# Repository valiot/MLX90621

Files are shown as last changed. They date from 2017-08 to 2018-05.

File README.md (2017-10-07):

### MLX90621 Arduino and Processing example code

Arduino and Processing code for the Melexis [MLX90621](http://www.melexis.com/Infrared-Thermometer-Sensors/Infrared-Thermometer-Sensors/Low-noise-high-speed-16x4-Far-Infrared-array-823.aspx) 16x4 thermopile array.

Includes R script to parse data files (which can be exported by Processing visualizer).

The MLX90621 FIRray temperature sensing device from Melexis utilizes the company’s non-contact temperature measurement technology to create a highly cost-effective thermography solution. Covering a -20°C to 300°C temperature range, this 16 x 4 element far infrared (FIR) thermopile sensor array produces a map of heat values for the target area in real time, avoiding the need to scan the area with a single point sensor or use an expensive microbolometer device.

In use in VU and Tilburg University temperature [cry detection project](http://www.pavlov.io/2015/07/01/detecting-crying-eyes/).

Implements MaxBot's MLX90621 [Arduino library](http://forum.arduino.cc/index.php?topic=126244.0) patched with KMoto's [minor change](http://forum.arduino.cc/index.php?topic=126244.msg2307588#msg2307588) in defaultConfig_H.

Also makes use of [nox771's i2c_t3 enhanced Teensy 3 Wire library](https://github.com/nox771/i2c_t3). This library allows a [Teensy 3.1](https://www.pjrc.com/store/teensy31.html) Arduino compatible USB development board to communicate with the MLX90621 over I2C/TWI.

TODO 2015-10-25: Refactor and clean up Processing visualizer.

##### Screenshot

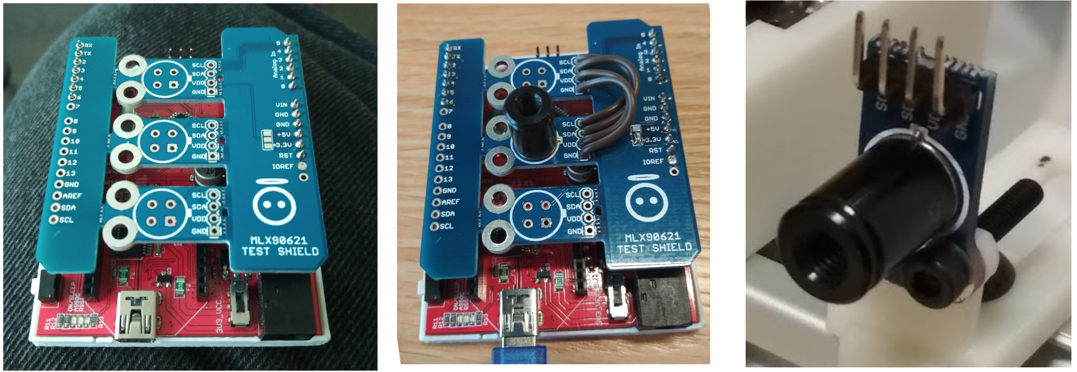
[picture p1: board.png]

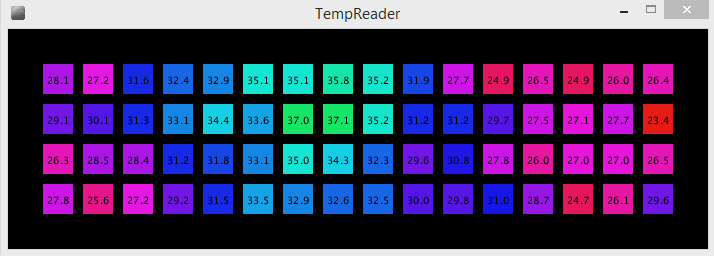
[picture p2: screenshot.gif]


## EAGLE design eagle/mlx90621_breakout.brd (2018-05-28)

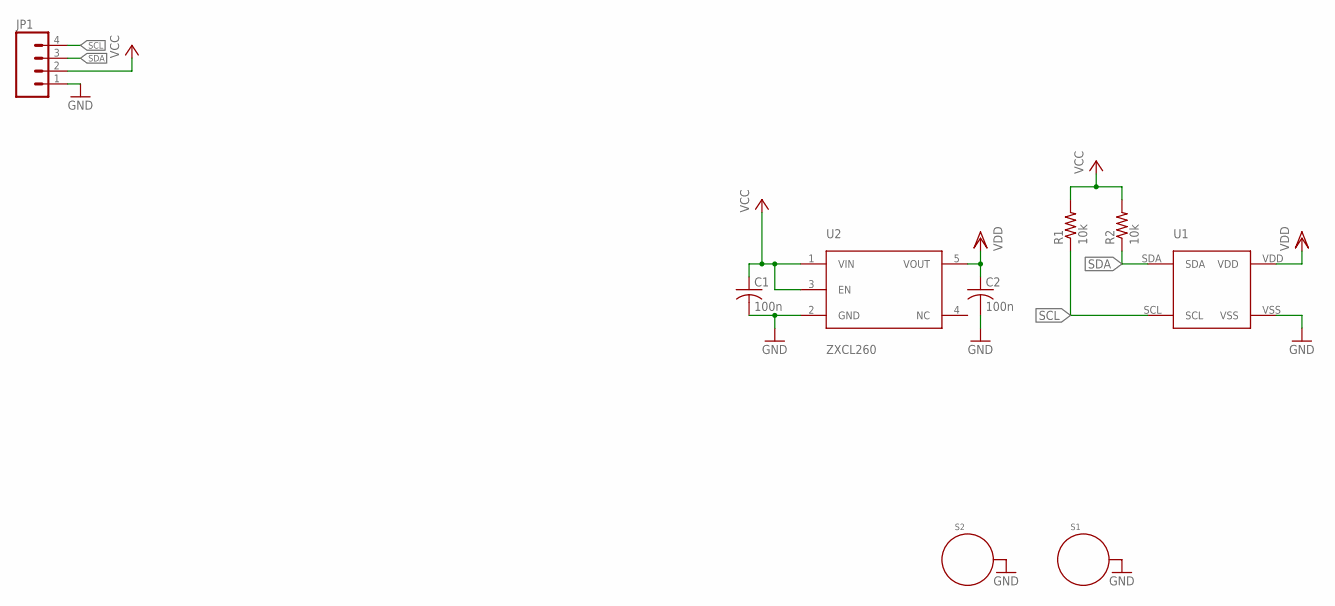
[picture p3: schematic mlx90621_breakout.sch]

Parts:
C1, C2: 100n; C0603
JP1: M04PTH; 1X04
R1, R2: 10k; R0603
S1, S2: STANDOFF_ELECTRICAL; STANDOFF-ELECTRICAL
U1: MLX90621BAD; MLX90621
U2: ZXCL260; VREG_SOT23-5

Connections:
GND: C1.2, C2.2, JP1.1, S1.P1, S2.P1, U1.VSS, U2.2 (GND)
SCL: JP1.4, R1.1, U1.SCL
SDA: JP1.3, R2.1, U1.SDA
VCC: C1.1, JP1.2, R1.2, R2.2, U2.1 (VIN), U2.3 (EN)
VDD: C2.1, U1.VDD, U2.5 (VOUT)

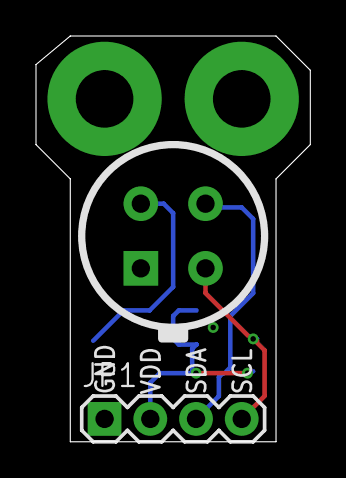
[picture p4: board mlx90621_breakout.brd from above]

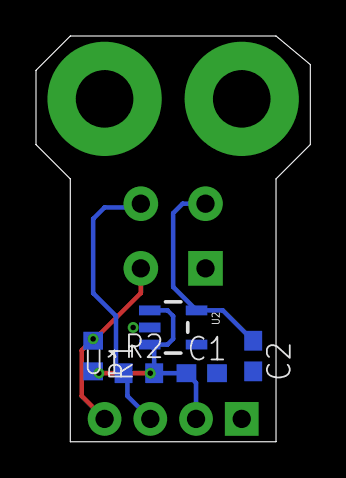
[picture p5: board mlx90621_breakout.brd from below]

Board: 2 copper layers, 15.2 x 22.5 mm, 9 parts (6 on the bottom side), 5 nets.

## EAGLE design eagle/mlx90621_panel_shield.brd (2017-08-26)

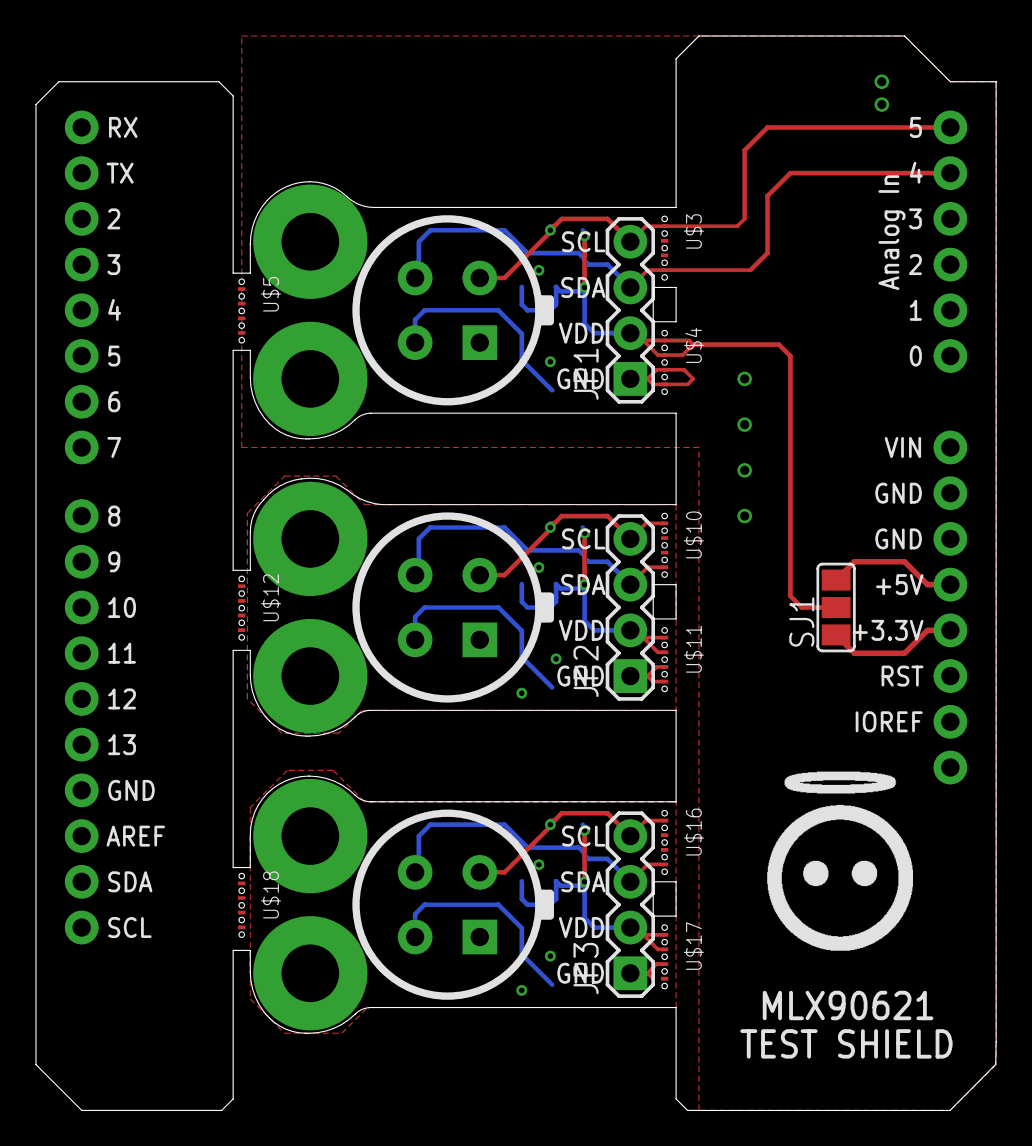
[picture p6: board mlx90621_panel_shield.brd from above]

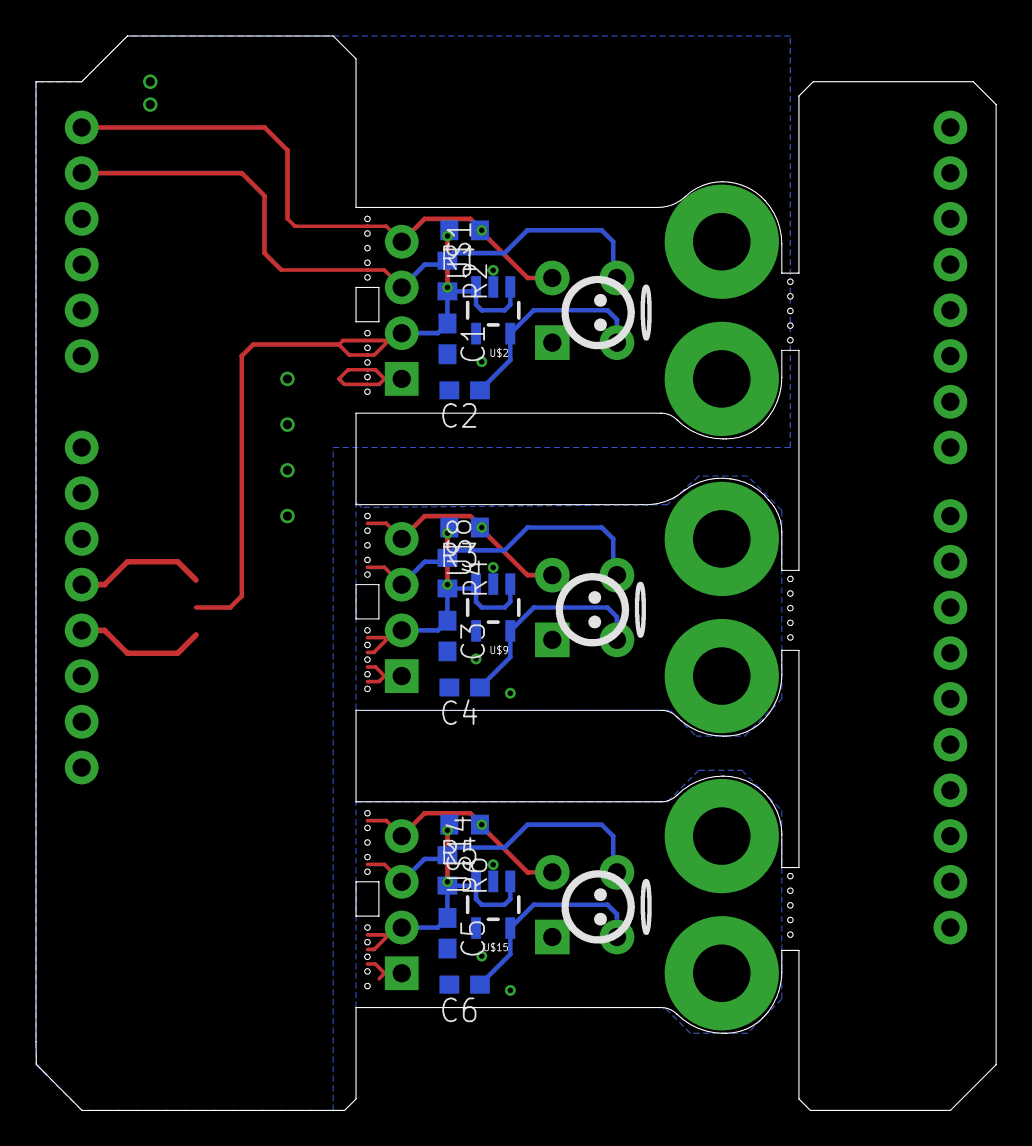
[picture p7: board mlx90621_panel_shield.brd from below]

Board: 2 copper layers, 53.3 x 59.7 mm, 42 parts (21 on the bottom side), 17 nets.

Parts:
C1, C2, C3, C4, C5, C6: 100n; C0603
E$1: DA_LOGO_10MM
E$2, E$3, E$4: DA_LOGO_5MM
J1: ARDUINO_R3_SHIELD; UNO_R3_SHIELD
JP1, JP2, JP3: 1X04
R1, R2, R3, R4, R5, R6: 10k; R0603
S1, S2, S3, S4, S5, S6: STANDOFF_ELECTRICAL; STANDOFF-ELECTRICAL
SJ1: SJ_2
U$1, U$8, U$14: MLX90621BAD; MLX90621
U$2, U$9, U$15: ZXCL260; VREG_SOT23-5
U$3, U$4, U$5, U$10, U$11, U$12, U$16, U$17, U$18: MOUSE-BITES-4

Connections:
+3V3: J1.3.3V, SJ1.1
+5V: J1.5V, SJ1.3
GND: C1.2, C2.2, J1.GND@0, J1.GND@1, JP1.1, S1.P1, S2.P1, U$1.VSS, U$2.2, U$4.3, U$4.4
GND1: C3.2, C4.2, JP2.1, S3.P1, S4.P1, U$8.VSS, U$9.2, U$11.3, U$11.4
GND2: C5.2, C6.2, JP3.1, S5.P1, S6.P1, U$14.VSS, U$15.2, U$17.3, U$17.4
SCL: J1.A5, JP1.4, R1.1, U$1.SCL, U$3.1
SCL1: JP2.4, R3.1, U$8.SCL, U$10.1
SCL2: JP3.4, R5.1, U$14.SCL, U$16.1
SDA: J1.A4, JP1.3, R2.1, U$1.SDA, U$3.4
SDA1: JP2.3, R4.1, U$8.SDA, U$10.4
SDA2: JP3.3, R6.1, U$14.SDA, U$16.4
VCC: C1.1, JP1.2, R1.2, R2.2, SJ1.2, U$2.1, U$2.3, U$4.1, U$4.2
VCC1: C3.1, JP2.2, R3.2, R4.2, U$9.1, U$9.3, U$11.1, U$11.2
VCC2: C5.1, JP3.2, R5.2, R6.2, U$15.1, U$15.3, U$17.1, U$17.2
VDD: C2.1, U$1.VDD, U$2.5
VDD1: C4.1, U$8.VDD, U$9.5
VDD2: C6.1, U$14.VDD, U$15.5

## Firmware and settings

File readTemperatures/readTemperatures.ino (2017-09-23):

/*
* A class for interfacing the Melexis 90620 Sensor from a Teensy 3.1
* Uses the 2c_t3 library for communication with the sensor
* 2013 by Felix Bonowski
* Based on a forum post by maxbot: http://forum.arduino.cc/index.php/topic,126244.msg949212.html#msg949212
* This code is in the public domain.
*
* Connection Instructions:
* Connect the Anode of a Silicon Diode to 3V Pin of Teensy. The Diode will drop ~0.7V, so the Cathode will be at ~2.7V. These 2.7V will be the supply voltage "VDD" for the sensor.
* Plug in the USB and measure the supply voltage with a multimeter! - it should be somewhere between 2.5V and 2.75V, else it will fry your precious sensor...
* ...disconnect USB again...
* Connect Teensy Pin 18 to 2.7V with a 4.7kOhm Resistor (Pullup)
* Connect Teensy Pin 19 to 2.7V with a 4.7kOhm Resistor (Pullup)
* Connect Teensy Pin 18 to I2C Data (SDA) Pin of Sensor
* Connect Teensy Pin 19 to I2C clock (SCL) Pin of Sensor
* Connect GND and 2.7V with a 100nF ceramic Capacitor.
* Connect the VSS Pin of the Sensor to GND.
* Connect the VDD Pin of the Sensor to 2.7V

 *  Created on: 9.7.2015
 *      Author: Robin van Emden
 */

#include <Arduino.h>
#include "MLX90621.h"

MLX90621 sensor; // create an instance of the Sensor class

void sendTemperatures(){
  for(int y=0;y<4;y++){ //go through all the rows
    Serial.print("[");
    
    for(int x=0;x<16;x++){ //go through all the columns
      double tempAtXY= sensor.getTemperature(y+x*4); // extract the temperature at position x/y
      Serial.print(tempAtXY);
         
      if (x<15) Serial.print(",");
    }
    Serial.print("]");
    if (y<3)Serial.print("~"); 
  }
  Serial.print("\n");
}

void setup(){ 
  Serial.begin(115200); //170ms a 19k2, 28ms a 115k2
  //Parpadea LED al reiniciarse el arduino
  pinMode(13, OUTPUT);
  for (int i = 0; i < 10; i++) 
    digitalWrite(13, !digitalRead(13));
  digitalWrite(13, LOW);
  //Serial.println(F("trying to initialize sensor..."));
  sensor.setRefreshRate(RATE_8HZ);
  sensor.setResolution(RES_17bit);
  sensor.setEmissivity(1.0);
  sensor.initialize (); // start the thermo cam
  //Serial.println(F("sensor initialized!"));
}
void loop(){  
  sensor.measure(true); //get new readings from the sensor
  sendTemperatures();
  delay(32);
};

/*
long startTime = micros();
//Measured stuff
long elapsed = micros() - startTime;
Serial.print("measure time = ");
Serial.print((float)elapsed/1000.0);
Serial.println("ms");
*/

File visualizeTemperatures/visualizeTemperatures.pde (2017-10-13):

/*
 *  VisualizeTemperatures.pde
 *
 *  A simple Processing Sketch which listens to a  
 *  Teensy 3.1+ Arduino board connected to a Melexis MLX90621
 *  and visualizes the temperature values measured by its 
 *  4x16 matrix as a color matrix 
 *
 *  WARNING!
 *  Per 11.10.2015 this script was adapted through quick and dirty copy and paste programming.
 *  This enabled me to demonstrate, and make use of, some alternative visualisations during measurement.
 *  The resulting code needs to be cleaned up and refactored.
 *
 *  Created on: 9.7.2015
 *      Author: Robin van Emden
 */

import org.jnativehook.GlobalScreen;
import org.jnativehook.NativeHookException;
import org.jnativehook.keyboard.NativeKeyEvent;
import org.jnativehook.keyboard.NativeKeyListener;
import java.util.logging.ConsoleHandler;
import java.util.logging.Formatter;
import java.util.logging.Level;
import java.util.logging.LogRecord;
import java.util.logging.Logger;

import processing.serial.*;
import java.util.LinkedList;
import java.util.Queue;
import java.util.Arrays; 
import java.text.SimpleDateFormat;
import java.util.Date;

public static final boolean  WRITE_TO_FILE = false;

//import controlP5.*;
//ControlP5 cp5;
//Slider s_max;
//Slider s_min;

PrintWriter output;
Serial serialConnection;
String sensorReading;
String[] serialString;  
String serialCheck;  
String portName_w = "eensy"; 
String portName_m = "cu.usbmodem1411"; //cu.usbserial-AJ03MS39
String portName_m2 = "cu.usbserial-AJ03MS39"; //
String portName_lin = "ttyUSB"; //
String portName_win = "COM"; //
int portNumber;  
int serialIndex;  
Double temperatureToString;
double[][] drawTemperatures2D;
double[][] temperatures2D;
double H, S, B;
boolean waitFirstNewline;
SMA[][] sma2D = new SMA[4][16];
SMA[][] sma2Dlong = new SMA[4][16];
SimpleDateFormat sdf;
double[] tempValues1D[];
PImage img;
double[][] quadrant = new double[4][16];
double[][] quadrantLong = new double[4][16];
boolean spaceCheck = false;
String pressedSpace = "";

//Min = morado, max = rojo
float min = 80.0;
float max = 100.0;
float gradMax = 20;

void setup() {
  size(700, 600);
  // log global keypress
  try {
    // Get the logger for "org.jnativehook" and set the level to warning.
    Logger logger = Logger.getLogger(GlobalScreen.class.getPackage().getName());
    logger.setLevel(Level.WARNING);
    GlobalScreen.registerNativeHook();
    GlobalScreen.addNativeKeyListener(new GlobalKeyListenerExample());
  }
  catch (NativeHookException ex) {
    System.err.println("There was a problem registering the native hook.");
    System.err.println(ex.getMessage());
  }


  for (int i = 0; i < 4; i++) {
    for (int j = 0; j < 16; j++) {  
      sma2D[i][j]= new SMA(6);
      sma2Dlong[i][j]= new SMA(40);
    }
  }  
  img = createImage(16, 4, RGB);
  img.loadPixels(); 
  if (WRITE_TO_FILE) {
    sdf = new SimpleDateFormat("yyyy_MM_dd_HH_mm_ss_SSS");  
    output = createWriter(sdf.format(new Date())+"_output.txt");
  }

  waitFirstNewline = false;
  sensorReading="";

  findSerialPort(); 
  try {
    serialConnection = new Serial(this, Serial.list()[portNumber], 115200);//19200);  
    
    serialConnection.bufferUntil('\n');
  } 
  catch (RuntimeException e) {
    noLoop();
    System.out.println("Connection to serial failed");
  }
}


public class GlobalKeyListenerExample implements NativeKeyListener {
  public void nativeKeyPressed(NativeKeyEvent e) {
    System.out.println("Key Pressed: " + NativeKeyEvent.getKeyText(e.getKeyCode()));
    if (NativeKeyEvent.getKeyText(e.getKeyCode()) == "Space") {
      spaceCheck = true;
    }
  }
  public void nativeKeyReleased(NativeKeyEvent e) {
    //System.out.println("Key Released: " + NativeKeyEvent.getKeyText(e.getKeyCode()));
  }
  public void nativeKeyTyped(NativeKeyEvent e) {
    //System.out.println("Key Typed: " + NativeKeyEvent  .getKeyText(e.getKeyCode()));
  }
}


void serialEvent (Serial serialConnection) {
  sensorReading = serialConnection.readStringUntil('\n');
  if (sensorReading != null) {
    if (waitFirstNewline) {
      sensorReading=trim(sensorReading);
    } else {
      serialConnection.clear();
      waitFirstNewline = true;
    }
  }
}

void draw() {
  background(0);
  translate(35, 35);
  fill(255);
  noStroke();
  
  drawTemperatures2D = parseInput(sensorReading);

  if (drawTemperatures2D!=null) {
    if (WRITE_TO_FILE) {

      if (spaceCheck) {
          pressedSpace = "1";
          spaceCheck = false;
      } else {
          pressedSpace = "0";
      }
      output.println(pressedSpace+"~"+sdf.format(new Date())+"~"+sensorReading); 
      output.flush();
    }

    for (int i = 15; i >= 0; i--) {  
      pushMatrix();
      for (int j = 0; j < 4; j++) {


        img.pixels[i+j*16]=getColor((float)drawTemperatures2D[j][i], min, max);
        fill(getColor((float)drawTemperatures2D[j][i], min, max));
        rect(0, 0, 30, 30);
        textSize(10);
        fill(0);
        temperatureToString = (double) Math.round(drawTemperatures2D[j][i] * 10) / 10;
        text(temperatureToString.toString(), 4, 20);
        translate(0, 40);
      }
      popMatrix();
      translate(40, 0);
    }
  }

//Imagen filtrada
  translate(-640, 185);
  img.filter(BLUR);
  img.updatePixels();
  pushMatrix();
  scale(-1.0, 1.0);
  image(img, -630, 0, 630, 150);
  popMatrix();

  translate(0, 185);
  fill(255);
  noStroke();
  if (drawTemperatures2D!=null) {
    int LT = 0, RT = 0, LB = 0, RB = 0;
    for (int i = 15; i >= 0; i--) {  
      pushMatrix();
      for (int j = 0; j < 4; j++) {
        double longValue = sma2Dlong[j][i].compute(drawTemperatures2D[j][i]);
        double shortValue = sma2D[j][i].compute(drawTemperatures2D[j][i]);
        //GRADIENTE
        double nowValue = longValue - shortValue;
        fill(gradientColor((float)nowValue, gradMax));
        rect(0, 0, 30, 30);
        textSize(10);
        fill(0);
        temperatureToString = -(double) Math.round(nowValue * 10) / 10;
        text(temperatureToString.toString(), 4, 20);
        translate(0, 40);
      }
      popMatrix();
      translate(40, 0);
    }
  }
  
  textSize(12);
  fill(1,0,1);
  text("Min: ", -640,170);
  text(int(min), -615,170);
  text("Max: ", -580,170);
  text(int(max), -555,170);
}


double[][] parseInput(String input) {
  String[] temperatureRows;
  temperatureRows = input.split("~");
  if (temperatureRows.length<4) return null;
  temperatures2D = new double[temperatureRows.length][];
  int i= 0;
  String[] temperatureCols;
  for (String row : temperatureRows) {
    row = row.substring(1, row.length()-1);
    temperatureCols = row.split(",");
    if (temperatureCols.length<16) return null;
    int j = 0;
    temperatures2D[i] = new double[temperatureCols.length];
    for (String col : temperatureCols) {
      try {
        temperatures2D[i][j++] = Double.parseDouble(col);
      }
      catch(NumberFormatException ex) {
        return null;
      }
    }
    i++;
  }
  return temperatures2D;
}
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

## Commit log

2017-08-20 Creada estructura del proyecto, basada en visualizador de ejemplo
    [mlx90621_breakout.brd, mlx90621_breakout.sch]
2017-08-20 Modificado delay de Arduino
2017-08-22 Modificado readTemperatures por libreria de Longjos
2017-08-22 eliminado circuito de ejemplo incorrecto (jpg)
2017-08-22 Agregados a gitignore archivos backup de EAGLE
2017-08-23 Finalizado ruteo de MLX90621 en shield (x1)
    [mlx90621_breakout.brd, mlx90621_breakout.sch]
2017-08-23 Finalizado diseño de panel shield
    [mlx90621_breakout.sch, mlx90621_panel_shield.brd]
2017-08-23 añadida carpeta gerber a gitignore
2017-08-23 Añadida lib de logos de DA
2017-08-23 Añadidos logos a shield
    [mlx90621_panel_shield.brd]
2017-08-26 modificado .gitignore (ignorar gerbers de eagle)
2017-08-26 modificado .gitignore (ignora archivos gerber de eagle)
2017-08-27 Modificado baudrate en Arduino (ahora 115k2), modificados prints por blink de LED
2017-08-27 Añadida referencia para benchmark de funciones
2017-08-27 Modif libreria MLX para ir a 400kHz
2017-08-27 Tests de modificacion de resolucion a libreria (a mano)
2017-08-27 Correccion de factor K -> C (273.15) y prueba emisividad
2017-08-28 Añadidas enumeraciones de resolucion y refresco a .h
2017-08-28 Añadidas propiedades y métodos de refresh, resolucion y emisividad a .h de sensor
2017-08-28 Implementados métodos de emisividad, refresh y resolucion en .cpp
2017-08-28 Actualizado ejemplo a nuevos métodos de la libreria de temperatura
2017-08-28 Modificado visualizador, ahora permite elegir rango de colores
2017-08-28 Mejorada visualizacion de gradiente
2017-08-28 Removida grasa de la interfaz (cuadros con promedios y umbrales)
2017-08-28 No guardar archivos por ahora y cambios en escala de color
2017-08-28 modificada resolucion de sensor de temperatura
2017-09-12 Añadidas medidas a PCB
    [mlx90621_breakout.brd]
2017-09-12 Prueba de MOSFET vs calentador inductivo
2017-09-14 añadido BOM de eagle a gitignore
2017-09-14 eliminados archivos .txt innecesarios (outputs de visualizer)
2017-09-18 Prueba de corriente y PWM MOSFET
2017-09-18 Añadidas fotos de pruebas corriente
2017-09-23 Borrados archivos de tests de termopares (Movidos a otro repo)
2017-09-23 Modificado breakout de sensor MLX (Añadidos bValues)
    [mlx90621_breakout.brd]
2017-09-23 Modificada velocidad de comunicacion de sensor (4Hz a 8Hz)
2017-09-23 Modificada funcion de deteccion de puerto COM para aceptar puertos de Windows (COM)
2017-10-01 Add board image
2017-10-13 agregado linux a lista de sistemas soportados por el serial del visualizador
2018-05-28 cleaned breakout for better component counting at BOM generation
    [mlx90621_breakout.brd, mlx90621_breakout.sch]
2018-05-28 changed References for ICs (U1, U2)
    [mlx90621_breakout.brd, mlx90621_breakout.sch]

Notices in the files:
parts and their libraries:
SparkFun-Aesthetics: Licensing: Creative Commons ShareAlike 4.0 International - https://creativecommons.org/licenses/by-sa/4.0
